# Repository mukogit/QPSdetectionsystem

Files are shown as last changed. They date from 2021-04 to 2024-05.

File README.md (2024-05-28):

# QPSdetectionsystem

Version 1.0.0

A platform for quadrature phase-shift detection using a PJRC Teensy 4.0, inexpensive photodiodes TSL257R and a couple of standard electrical components, soldered to custom PCB board inside a custom 3d-printed housing.

This repository contains the electronics schematics, list of components, code (python&C) to construct and run the QPS detection unit.

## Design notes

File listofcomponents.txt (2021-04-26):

1) 	2x Waveguide (we used 1mm diameter glass rods)
2)	2x BNC plugs  
3)	2x Light to Voltage sensor (TLV257R)
4)	3x 100nF Capacitor
5)	PJRC Teensy 4.0 microcontroller
6)	8x Nuts/Bolts (M3)
7)  	USB-cable
8)	electrical wiring 

Optional: - Operational amplifier LMC6042
	  - Resistors of choice for amplification

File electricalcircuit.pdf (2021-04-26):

GITHUB REPOSITORY - ELECTRONIC CIRCUIT

Electronic circuit of the detection unit. If there is only a little light incident on the detectors, it is possible to amplify the measured voltage using a operational amplifier, e.g. a LMC6042. Therefore "IN B+" should be shortcut to "OUT B" and "IN A+" should be shortcut to "OUT A". The wanted amplification is then chosen by a suitable ratio of the resistors R1 and R2. All 5 V input voltages are stabilized by 100 nF capacitors, see also "pcb_description.pdf" for exact wiring.

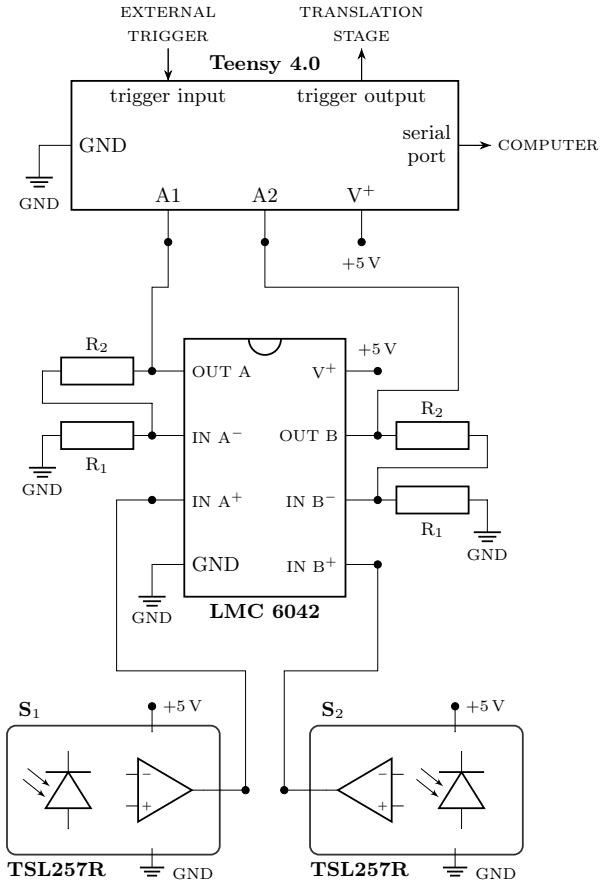
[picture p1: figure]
Teensy 4.0; serial; port; computer; GND; trigger input; external; trigger; trigger output; translation; stage; LMC 6042; OUT B; OUT A; TSL257R

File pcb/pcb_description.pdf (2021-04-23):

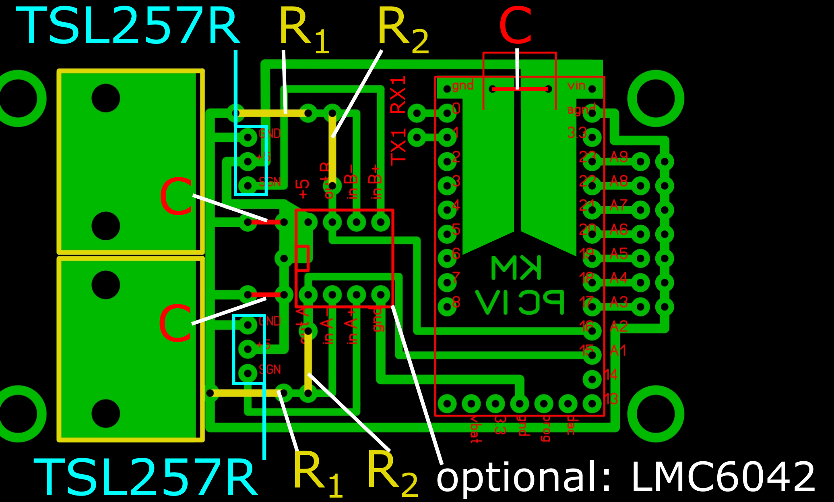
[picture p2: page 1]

TSL257R

TSL257R

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
optional: LMC6042

TX1 RX1

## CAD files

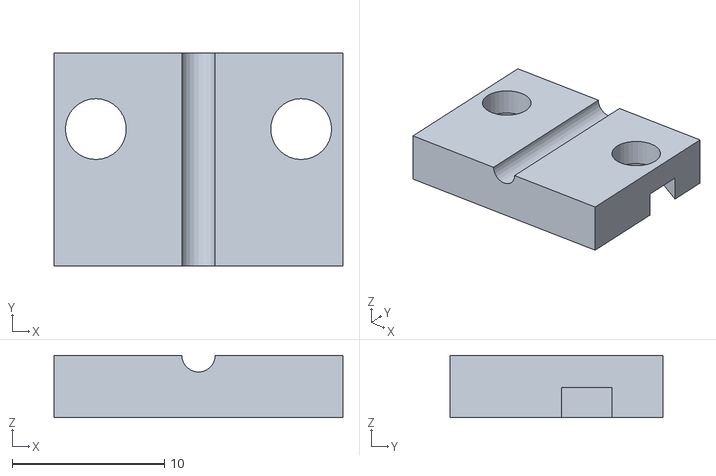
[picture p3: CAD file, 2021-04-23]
stl-files/waveguide_clamp .stl
19.0 x 14.0 x 4.10

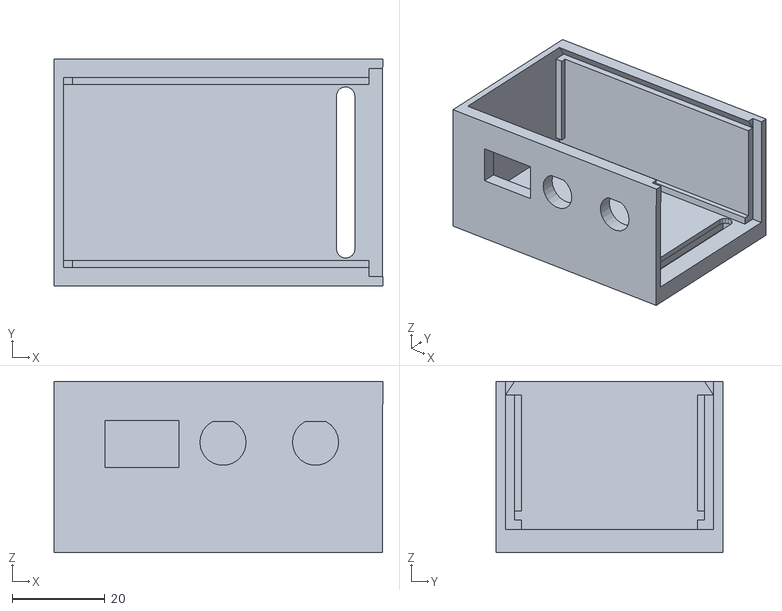
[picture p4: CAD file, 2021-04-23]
stl-files/box.stl
71.1 x 49.0 x 37.0

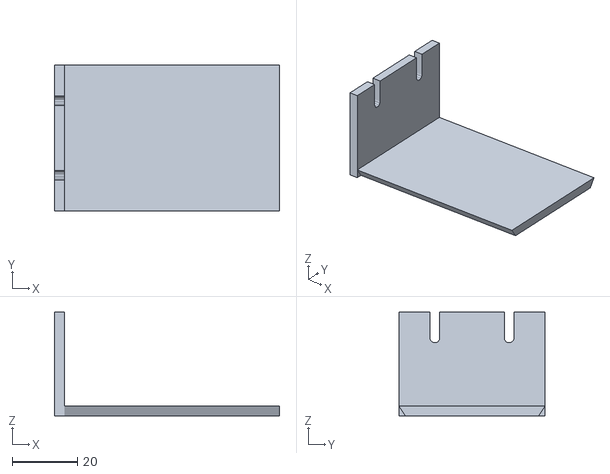
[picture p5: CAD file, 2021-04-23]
stl-files/box_lid.stl
69.0 x 44.8 x 31.8

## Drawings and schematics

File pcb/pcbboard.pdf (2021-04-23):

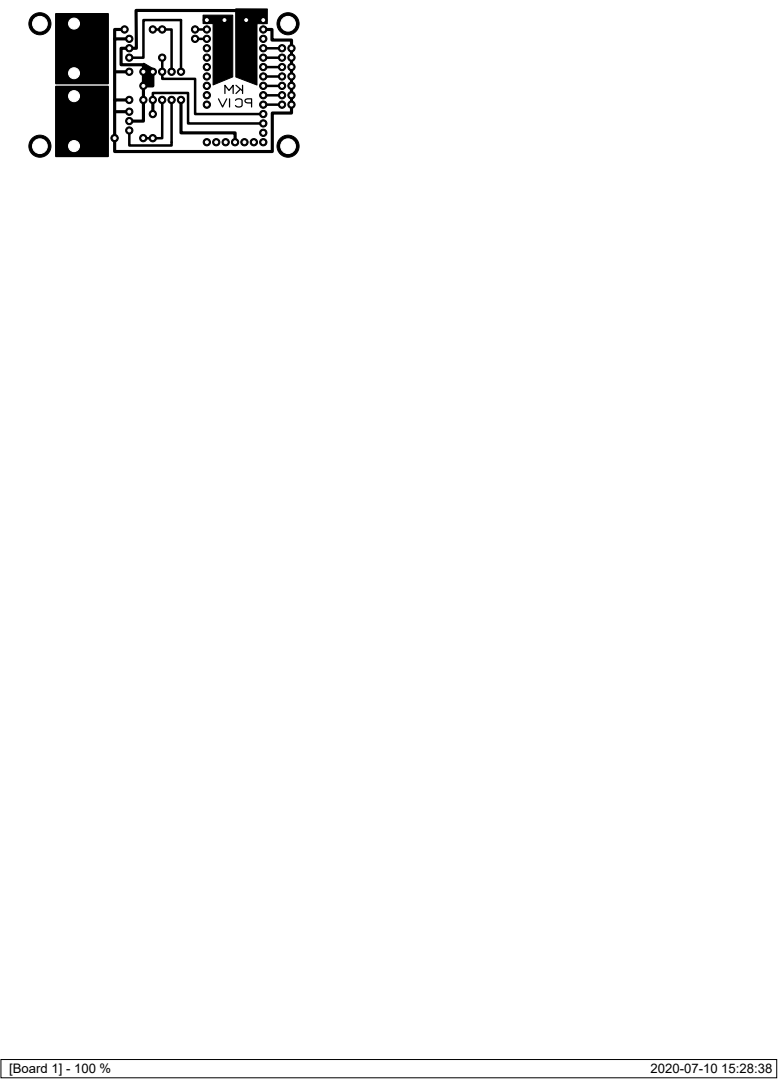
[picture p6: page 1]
[Board 1] - 100 %

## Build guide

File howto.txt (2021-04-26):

PCB board: 
1.	You find the printable pcb layout: "https://github.com/mukogit/QPSdetectionsystem/blob/main/pcb/pcbboard.pdf"
2.	Make the PCB board

Housing:
1. You can 3D-print the following files to be able to mount the pcb board in an opaque housing, and to clamp the waveguides in front of the detectors
	1)	Box
	2)	Lid
	3)	waveguide_clamp
	
You find all .stl files here: "https://github.com/mukogit/QPSdetectionsystem/tree/main/stl-files"

Mounting:
1)  Get all parts listed in: "https://github.com/mukogit/QPSdetectionsystem/blob/main/listofcomponents.txt"
2)	Solder the components to the pcb-board as illustrated in: - "https://github.com/mukogit/QPSdetectionsystem/blob/main/pcb/pcb_description.pdf"
															  - "https://github.com/mukogit/QPSdetectionsystem/blob/main/electricalcuircuit.pdf"
3)	Mount the pcb-board inside the 3D-printed box.															  
4)  Fasten waveguides inside the box to the pcb-board using the waveguide_clamps.

Data recording:
1)	You find the teensy and python code to record data here: "https://github.com/mukogit/QPSdetectionsystem/tree/main/software"
2)	The Teensy microcontroller will record the voltage from your two sensors at 5 kHz and send them on the serial port to the computer.
3)  If you run the python file "main.py", you connect to your Teensy (by choosing the right COM port) and the data is saved to the same folder as "main.py".

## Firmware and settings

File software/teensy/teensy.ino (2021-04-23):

int v1; //voltage at S@$_1$@
int v2; //voltage at S@$_2$@
char data[18];
int trigger = 0;
int trigger_in = 7;
int trigger_out = 8;
unsigned long time;                                                // microsecond timer
unsigned long Notch;

void setup() {
    Serial.begin(2000000); 	  //baud rate
    analogReadResolution(12); //12-bit res.

    pinMode(A1, INPUT);
    pinMode(A2, INPUT);
    pinMode(trigger_in, INPUT);
    pinMode(trigger_out, OUTPUT);
}

bool Delay(unsigned long dtime) {
    unsigned long rt = micros();
    if (abs(rt - Notch) > dtime ) {
        Notch = rt;
        return true;
    }
    else return false;
}  
  
void loop() {
    trigger = digitalRead(trigger_in);
    
    if (trigger == HIGH) {
        digitalWrite(trigger_out, HIGH);
    }
    
    time = (int) micros(); //get time in µs
    
    if (Delay(200)) {
        v1 = analogRead(A1);
        v2 = analogRead(A2);
        sprintf(data, "%09i%04i%04i", time, v1, v2);
    }
    
    if (trigger == HIGH) {    
        Serial.println(data); //send data
        for(int i = 0; i < 18;  ++i ) {
    	    data[i] = (char)0;
        }
        Serial.flush();
    }
}

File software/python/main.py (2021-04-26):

import serial
import os
import datetime
import numpy as np

port = 'COM1'

teensy, data = None, None
baud = 2000000
voltage1_offset = 900 #measurement dep. value
voltage2_offset = 600 #measurement dep. value
pc = 0 				  #2@$\pi$@ phasecounter
phase_offset = 0 		  #phase offset    
pidiff = 6

teensy = serial.Serial(port, baudrate=baud)

directory = os.getcwd()
now = datetime.datetime.now()
filename = now.strftime('%y%m%d_%H%M%S')

path = ('{0}\\data\\{1}_data.csv'.format(directory, filename))
outfile = open(path, 'w+')
outfile.write('time,v1,v2,unwrapped phase,position\n')

data_acquisition = True

while data_acquisition:
    data = teensy.readline()
    data = data[0:-2].decode('utf-8')
    
    #extract time and voltages
    time = int(data[0:9]) / 1000000
    v1 = int(data[9:13])  #voltage at S@$_1$@
    v2 = int(data[13:17]) #voltage at S@$_2$@
    
    #offset around zero and normalize
    v1_lev = v1 - voltage1_offset
    v2_lev = v2 - voltage2_offset
    _sqrt = np.sqrt(v1_lev**2 + v2_lev**2)
    v1_norm = v1_lev / _sqrt
    v2_norm = v1_lev / _sqrt
    
    #unwrap phase
    wrap_phase = np.arctan2(v2_norm, v1_norm)
    delta_wrap_phase = wrap_phase - phase_offset
    if delta_wrap_phase > pidiff:
        pc -= 1
    elif delta_wrap_phase < -pidiff:
        pc += 1
    phase_offset = wrap_phase
    phase = wrap_phase + (2*np.pi * pc)
    
    #convert phase to position
    position = phase / (4*np.pi) * 632.8e-9 #[m]
    outfile.write('{0},{1},{2},{3:.4f},{4:.4f}\n'.format(time, v1, v2, phase, position))
